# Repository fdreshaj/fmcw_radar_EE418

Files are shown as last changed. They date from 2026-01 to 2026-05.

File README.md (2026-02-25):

# fmcw_radar_EE418
FMCW Radar Design at 26.5 - 40 GHz

Initial Systems Level Overview
Bistatic Design
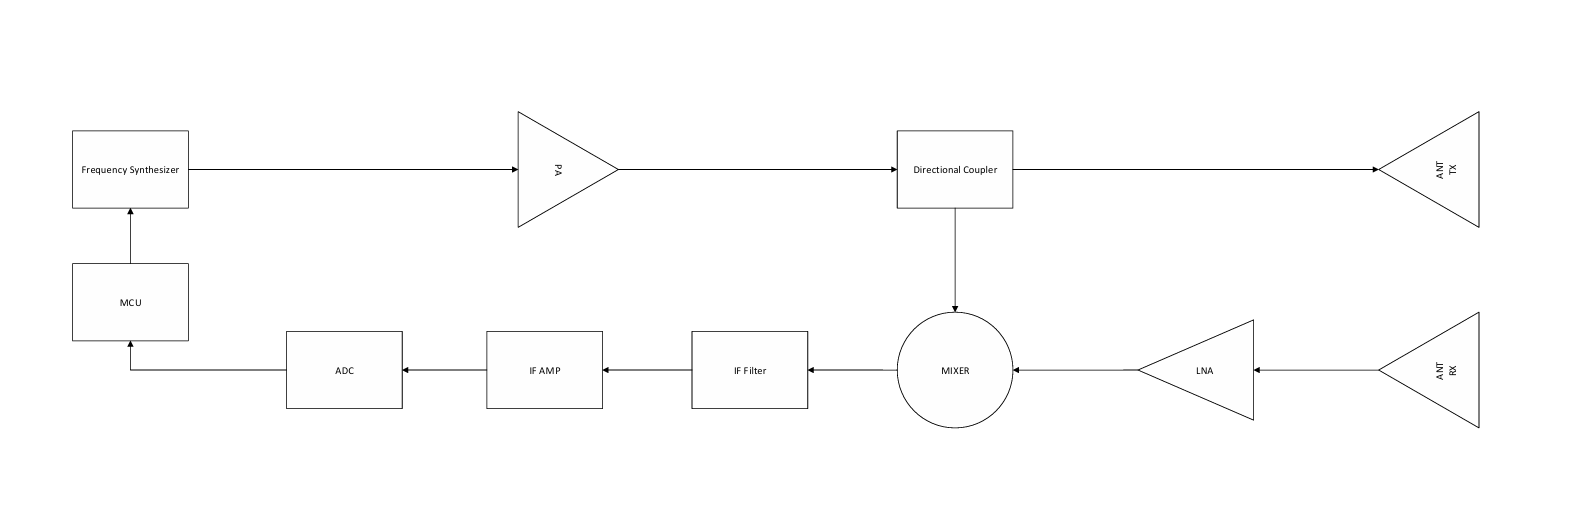
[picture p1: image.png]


Monostatic Design

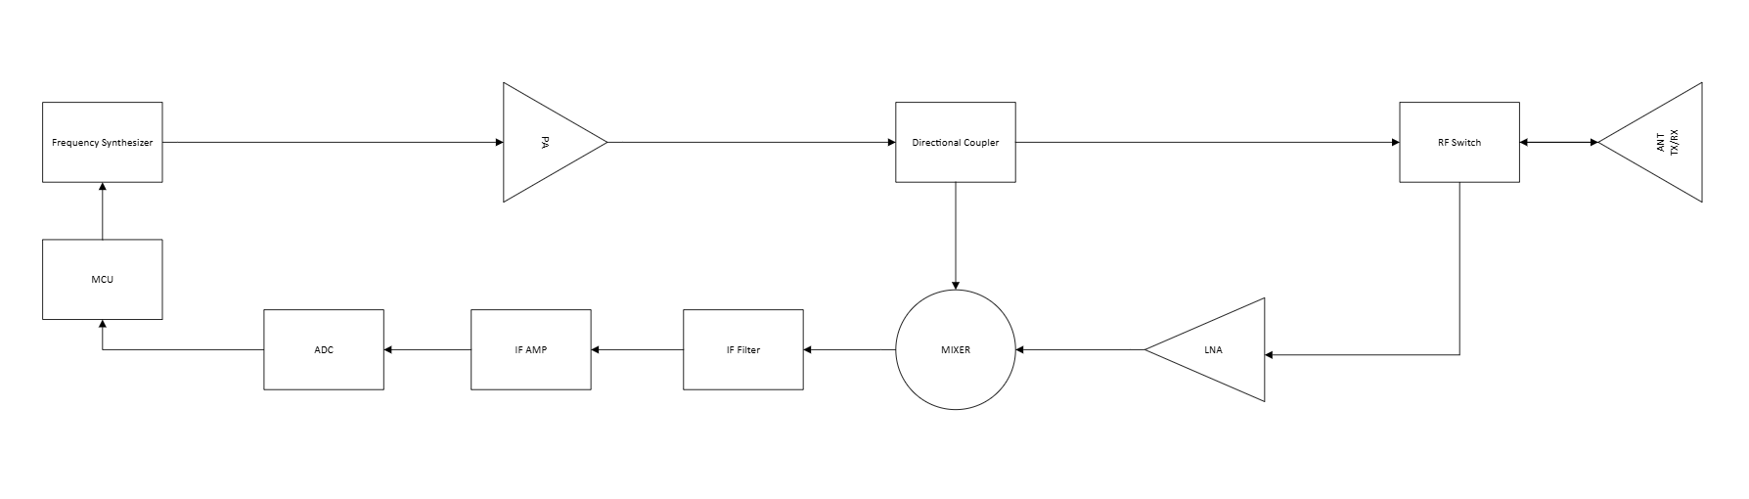
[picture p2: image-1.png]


Initial Parts Search Tx bistatic:

MCU 

STM32H730VBT6

Synthesizer 
	ADF4371 62.5MHz - 32 GHz
	Refer to datasheet for more info 
	3.3V, 5V, min 200mA
	Pout = -7dBm at 30 GHz

PA  
    MAAP-118260 18-26 GHz 28.5 dB,28.5 dBm, 24 QFN
    MAAP-011319 24-30 GHz 24 dB, 27 dBm PSAT 24 QFN

Dir Coupler 
    FPC07181 20GHz ~ 40GHz 20dB 0.3dB IL, 15 dB RL

ADC

    AD4080 20 Bit 40 MSPS Differential SAR 

LNA

	PMA3-24323LN+ 24-32 GHz, fluctuates around 14.5 to 15.1 dB
	Operating Vs 4.75-5.25

TX Mixer

	ADAR2001 In 2.5-10 GHz
	2.5V analog supply, 1.8 digital supply, 4x Freq 
	Differential

RX Mixer

	ADAR2004 RF In 10-40 GHz, LO In  2.4-10.1 GHz, IF Out  0-800 MHz
	2.5V analog supply, 1.8V digital, Gain Range 21-41 dB
	Differential

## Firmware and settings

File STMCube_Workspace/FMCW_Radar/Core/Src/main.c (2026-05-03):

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
/* Includes ------------------------------------------------------------------*/
#include "main.h"

/* USER CODE BEGIN Includes */
#include "adar2001.h"
#include "adar2004.h"
#include "adf4372.h"
#include "dac7563.h"
#include <stdint.h>
/* USER CODE END Includes */

/* USER CODE BEGIN PTD */
//uint16_t test_dac_value = 4000;
/* USER CODE END PTD */

SPI_HandleTypeDef hspi1;
SPI_HandleTypeDef hspi2;

TIM_HandleTypeDef htim3;
TIM_HandleTypeDef htim4;

PCD_HandleTypeDef hpcd_USB_FS;

/* USER CODE BEGIN PV */
uint16_t dac_value = DAC_MIN_CODE;
uint16_t dac_increment = (DAC_MAX_CODE - DAC_MIN_CODE) / CHIRP_STEPS; // 2
volatile uint8_t dac_update_flag = 0;
volatile uint8_t dac_reset_flag = 0;
volatile uint8_t start_chirp_flag = 0;
uint8_t chirp_active = 0;
uint32_t chirp_step_count = 0;
uint32_t idle_count = 0;

volatile uint32_t reset_count = 0;   // debug counter
volatile uint32_t update_count = 0;  // debug counter
/* USER CODE END PV */

void SystemClock_Config(void);
static void MX_GPIO_Init(void);
static void MX_USB_PCD_Init(void);
static void MX_SPI2_Init(void);
static void MX_SPI1_Init(void);
static void MX_TIM3_Init(void);
static void MX_TIM4_Init(void);
/**
  * @brief  The application entry point.
  * @retval int
  */
int main(void)
{

  /* MCU Configuration--------------------------------------------------------*/

  /* Reset of all peripherals, Initializes the Flash interface and the Systick. */
  HAL_Init();

  /* Configure the system clock */
  SystemClock_Config();

  /* Initialize all configured peripherals */
  MX_GPIO_Init();
  MX_USB_PCD_Init();
  MX_SPI2_Init();
  MX_SPI1_Init();
  MX_TIM3_Init();
  MX_TIM4_Init();
  /* USER CODE BEGIN 2 */
  DAC7563_Init(&hspi2);
  ADF4372_Init(&hspi1);
  ADAR2001_Init(&hspi1);
  ADAR2004_Init(&hspi1);

  // Start Idle timer - chirp timer started by TIM4 callback
  HAL_TIM_Base_Start_IT(&htim4);
  /* USER CODE END 2 */

  /* Infinite loop */
  /* USER CODE BEGIN WHILE */
  while (1)
  {
      if (dac_reset_flag)
      {
          dac_reset_flag = 0;
          dac_update_flag = 0;
          reset_count++;  // increment every time reset fires
          DAC7563_Write(&hspi2, DAC_WRITE_UPDATE_A, DAC_MIN_CODE);
      }
      else if (dac_update_flag)
      {
          dac_update_flag = 0;
          update_count++;  // increment every time update fires
          DAC7563_Write(&hspi2, DAC_WRITE_UPDATE_A, dac_value);
      }

      if (start_chirp_flag)
      {
          start_chirp_flag = 0;
          dac_value = DAC_MIN_CODE;
          HAL_TIM_Base_Start_IT(&htim3);
      }
  }
  /* USER CODE END WHILE */

}

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
/* USER CODE BEGIN 4 */
void HAL_TIM_PeriodElapsedCallback(TIM_HandleTypeDef *htim)
{
    if (htim->Instance == TIM3)
    {
        if (dac_value >= DAC_MAX_CODE)
        {
            dac_update_flag = 0;
            dac_reset_flag = 1;
            dac_value = DAC_MIN_CODE;
            HAL_TIM_Base_Stop_IT(&htim3);
            HAL_TIM_Base_Start_IT(&htim4);
        }
        else
        {
            dac_value += dac_increment;
            dac_update_flag = 1;
        }
    }

    if (htim->Instance == TIM4)
    {
        HAL_TIM_Base_Stop_IT(&htim4);
        start_chirp_flag = 1;  // Signal main loop to start chirp
    }
}
/* USER CODE END 4 */
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


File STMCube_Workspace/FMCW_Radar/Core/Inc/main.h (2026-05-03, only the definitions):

#define NSS4_ADAR2004_Pin GPIO_PIN_2
#define NSS4_ADAR2004_GPIO_Port GPIOA
#define NSS3_ADAR2001_Pin GPIO_PIN_3
#define NSS3_ADAR2001_GPIO_Port GPIOA
#define NSS_ADF4372_Pin GPIO_PIN_4
#define NSS_ADF4372_GPIO_Port GPIOA
#define DAC_NCLR_Pin GPIO_PIN_2
#define DAC_NCLR_GPIO_Port GPIOB
#define DAC_NLDAC_Pin GPIO_PIN_10
#define DAC_NLDAC_GPIO_Port GPIOB
#define NSS_DAC7563_Pin GPIO_PIN_12
#define NSS_DAC7563_GPIO_Port GPIOB

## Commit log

2026-01-27 added kicad project
    added kicad project
    [ADC.kicad_sch, MCU.kicad_sch, Synth.kicad_sch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]
2026-03-02 KiCAD files
    What I currently have for the KiCAD of the transmission. Let me know if there's any issues
    [GroundingTXRX.kicad_sch, RX_Side.kicad_sch, TX_RX.kicad_pcb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]
2026-03-18 minor changes
    minorchanges
    [MCU.kicad_sch]
2026-03-19 added MCU PSU VCO
    [MCU.kicad_sch, fmcw_radar_sch.kicad_sch, psu.kicad_sch]
2026-03-24 board changes
    board changes
    [DAC.kicad_sch, MCU.kicad_sch, Synth.kicad_sch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]
2026-03-27 Add files via upload
    The pcb_editor file in this group has the profile for the vivaldi I designed in CST. It uses the standard 4 layer stackup from JLCPCB's controlled impedance stackup.
    [diff_vivaldi.kicad_pcb, diff_vivaldi.kicad_sch]
2026-03-29 Layout of controller board
    [DAC.kicad_sch, MCU.kicad_sch, fmcw_radar_sch.kicad_pcb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]
2026-03-30 CHANGES
    changes
    [DAC.kicad_sch, MCU.kicad_sch, Synth.kicad_sch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]
2026-03-30 Routing
    Routing
    [DAC.kicad_sch, fmcw_radar_sch.kicad_pcb, psu.kicad_sch]
2026-03-30 RF Board Sch
    RF Board Sch
    [Connections.kicad_sch, Up_Down_Converter.kicad_pcb, Up_Down_Converter.kicad_sch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]
2026-04-01 rf changes
    rf changes
    [Up_Down_Converter.kicad_pcb, downconverter.kicad_sch, upconverter.kicad_sch]
2026-04-01 Create FMCW_Radar.ioc
    Added the STM32CubeIDE project for the Firmware
2026-04-02 Added pin functions
2026-04-02 initial
    initial
    [Up_Down_Converter-B_Cu.gbr, Up_Down_Converter-B_Mask.gbr, Up_Down_Converter-B_Paste.gbr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]
2026-04-06 a lot of updates
    usb power delivery + finishing touches
    [MCU.kicad_sch, Power_Delivery.kicad_pcb, Power_Delivery.kicad_sch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]
2026-04-06 Silkscreen finishing
    Silkscreen finishting
    [Power_Delivery.kicad_pcb, RefP.kicad_sch, Up_Down_Converter.kicad_pcb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]
2026-04-06 Gerbers
    Gerbers
    [Power_Delivery-B_Cu.gbr, Power_Delivery-B_Mask.gbr, Power_Delivery-B_Paste.gbr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]
2026-04-07 final changes to RF board
    final changes to RF board + grbs
    [Power_Delivery.kicad_pcb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]
2026-04-08 changes from yesterday
    changes from yesterday
    [Power_Delivery-B_Cu.gbr, Power_Delivery-B_Mask.gbr, Power_Delivery-B_Paste.gbr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]
2026-04-25 Add SPI driver files
2026-04-27 Added functions to .c src files and got project to compile
    [MCU.kicad_sch]
2026-07-07 second board
    second board
    [RefP.kicad_sch, Up_Down_Converter.kicad_sch, biasing.kicad_sch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]

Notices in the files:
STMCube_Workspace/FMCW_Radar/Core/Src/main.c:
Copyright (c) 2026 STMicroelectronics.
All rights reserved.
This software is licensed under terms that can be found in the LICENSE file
